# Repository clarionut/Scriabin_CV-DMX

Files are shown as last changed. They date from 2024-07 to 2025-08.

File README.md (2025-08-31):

# Scriabin_CV-DMX

A two channel CV-DMX converter based on an Arduino Pro Mini microcontroller.

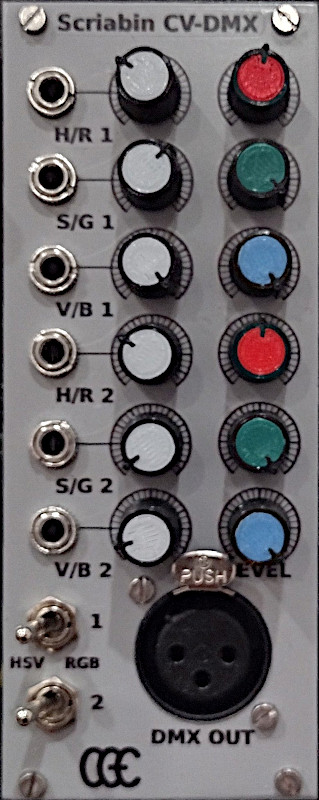
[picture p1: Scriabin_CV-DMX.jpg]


Named for the famously synaesthetic composer Scriabin, this module was designed to allow RGB LED PAR cans to be voltage controlled by an analogue modular synthesiser.
Each of the two channels can be controlled in the RGB (red, green, blue) or HSV (hue, saturation, value) colourspace, giving three control inputs per channel.
Each individual input has an attenuator for the CV input and an initial value potentiometer, so all colours are accessible without using the CV inputs.
In RGB mode the inputs control the red, green and blue channels individually, simple to understand but harder to use. Consequently HSV is probably the more useful colourspace, where setting the saturation and value initial values to maximum allows all hues to be accessed using just one CV input. This is also the reason for using HSV rather than the HSL (hue, saturation, lightness) colourspace, where the fully saturated colours are found at 100% saturation, 50% lightness.

There is also a 'hidden' mode on each channel (hidden mainly because of lack of space on the panel!). With the mode switch in the centre-off position the corresponding
channel will enter 'Scriabin mode' which converts the incoming Red/Hue CV into quantised light colours according to the scheme used by Scriabin in his ['Clavier à lumières'](https://en.wikipedia.org/wiki/Clavier_%C3%A0_lumi%C3%A8res).
The colours are: C - red; C# - purple; D - yellow; D# - flesh; E - sky blue; F - deep red; F# - bright blue; G - orange; G# - lilac; A - green; A# - rose; B - blue (this makes more sense if ordered by the circle of fifths - C - red; G - orange; D - yellow; A - green; E - sky blue; B - blue; F# - bright blue; C# - purple; G# - lilac; D# - flesh; A# - rose; F - deep red).
In this mode the input CV range should be adjusted so that successive octaves give the same colour. The tracking isn't perfect but should be good over about 2 1/2 octaves.
The Green/Saturation control has no effect in this mode but the Blue/Value control can be used to fade the light in and out, though the colours are increasingly inaccurate at low brightness.

The hardware is based on an Arduino Pro Mini driving a MAX485 RS-485 transceiver chip, as used in some of the commercial Arduino DMX shields.
The CV inputs have protection against out-of-range voltage inputs, but there is no isolation on the MAX485 (again like many of the commercial DMX shields).
Consequently the synthesiser and the light units must be powered from the same electrical circuit to avoid potentially dangerous voltages entering the synth.

The KiCad schematic and board layout use some custom symbols and footprints, so you will need to add my [kiCad_libraries](https://github.com/clarionut/kiCad_libraries)
before using these files.

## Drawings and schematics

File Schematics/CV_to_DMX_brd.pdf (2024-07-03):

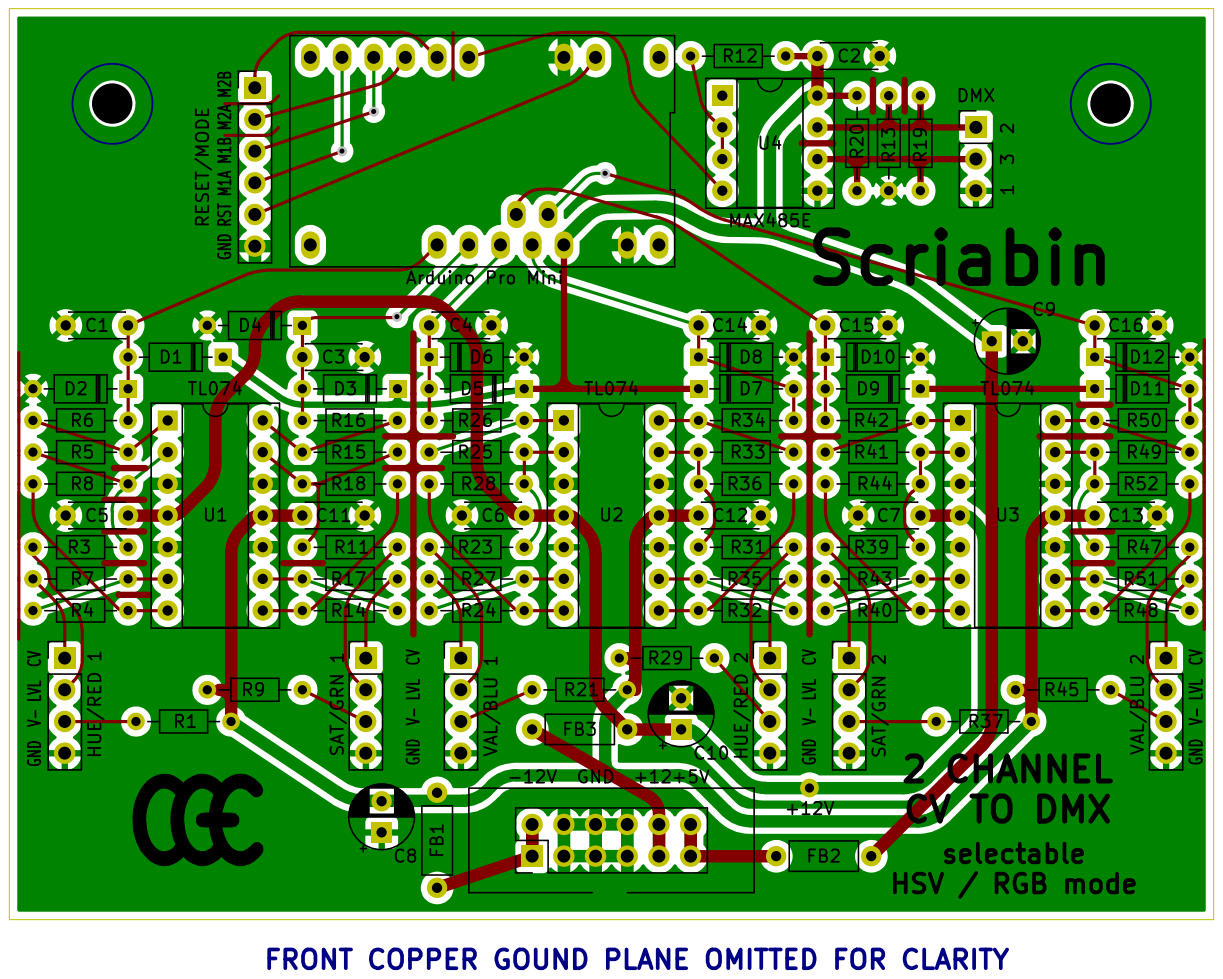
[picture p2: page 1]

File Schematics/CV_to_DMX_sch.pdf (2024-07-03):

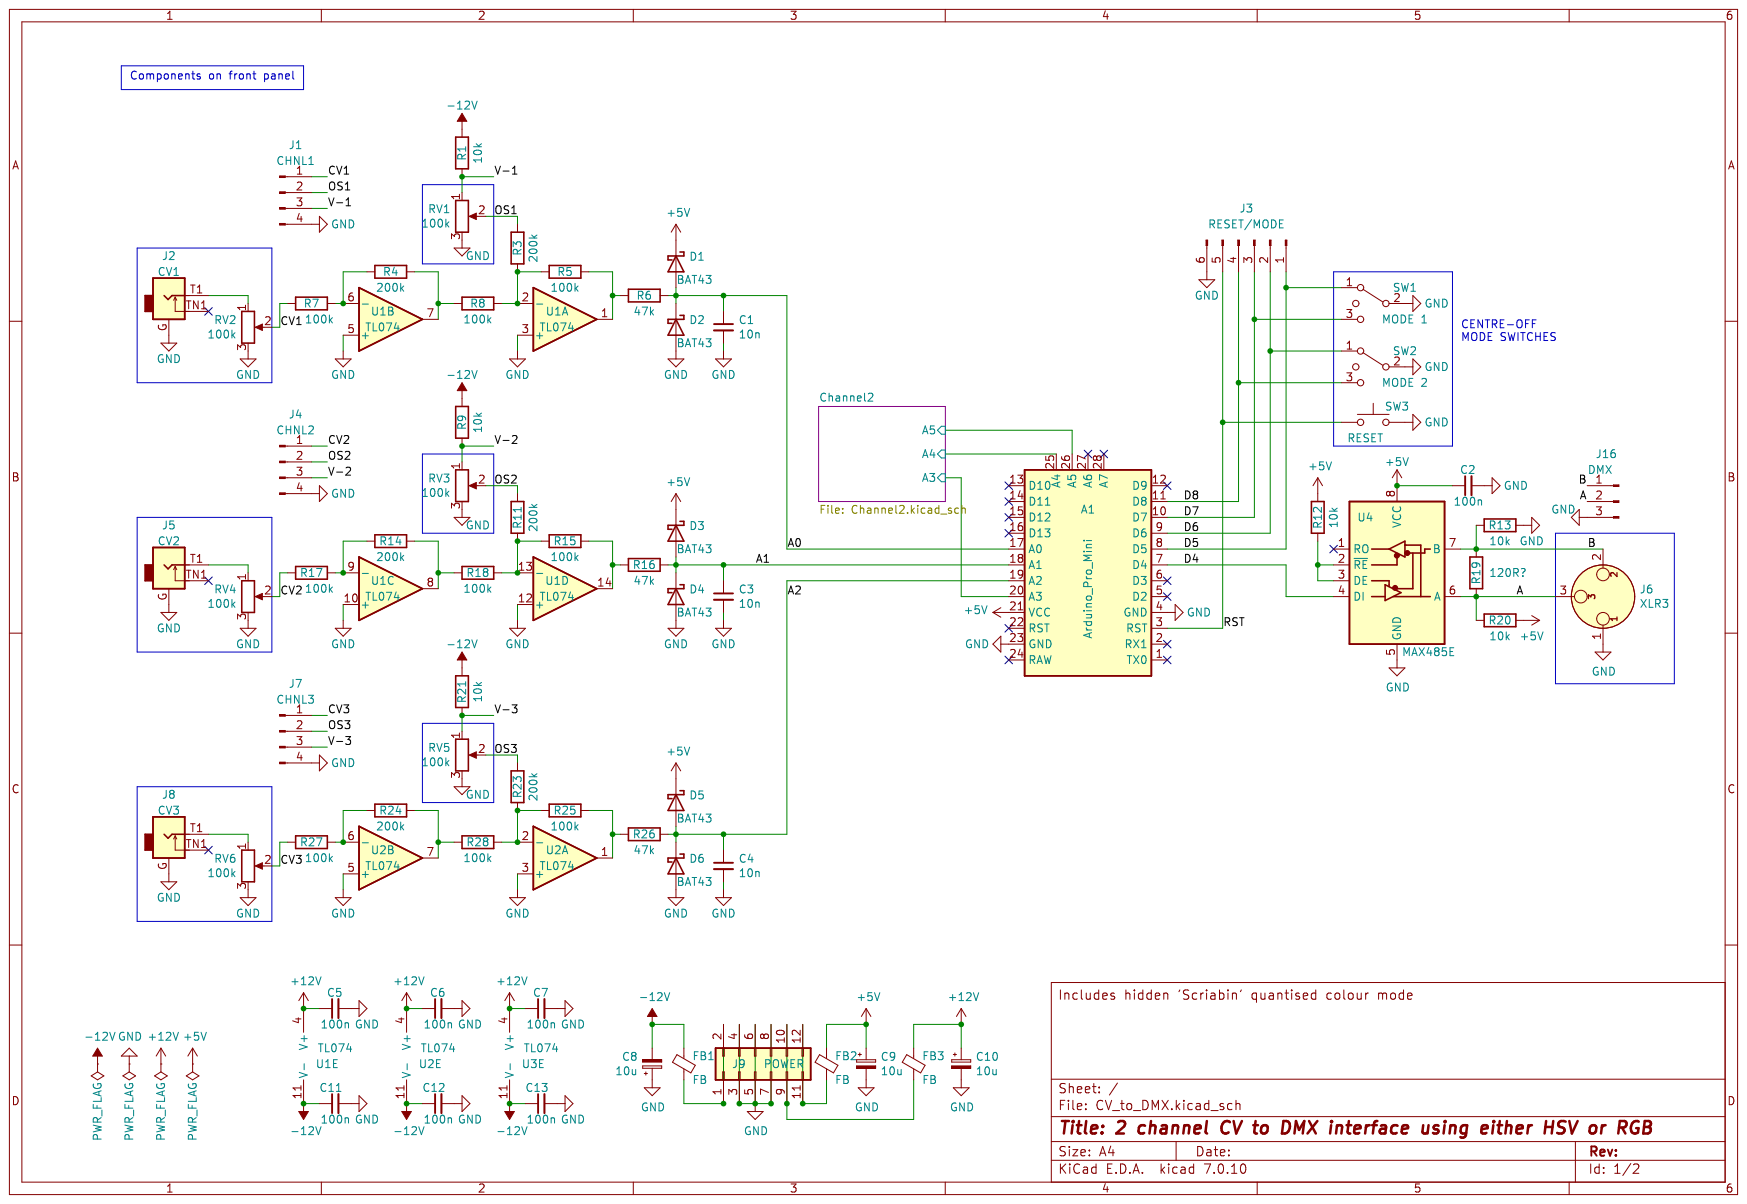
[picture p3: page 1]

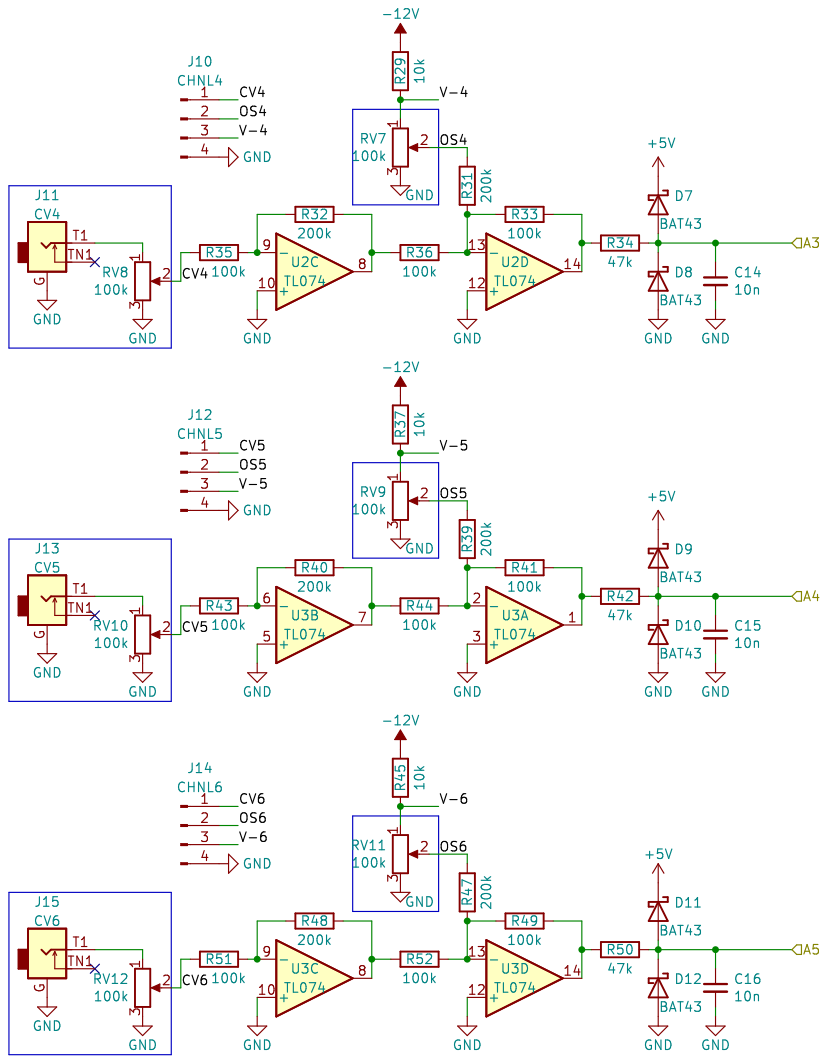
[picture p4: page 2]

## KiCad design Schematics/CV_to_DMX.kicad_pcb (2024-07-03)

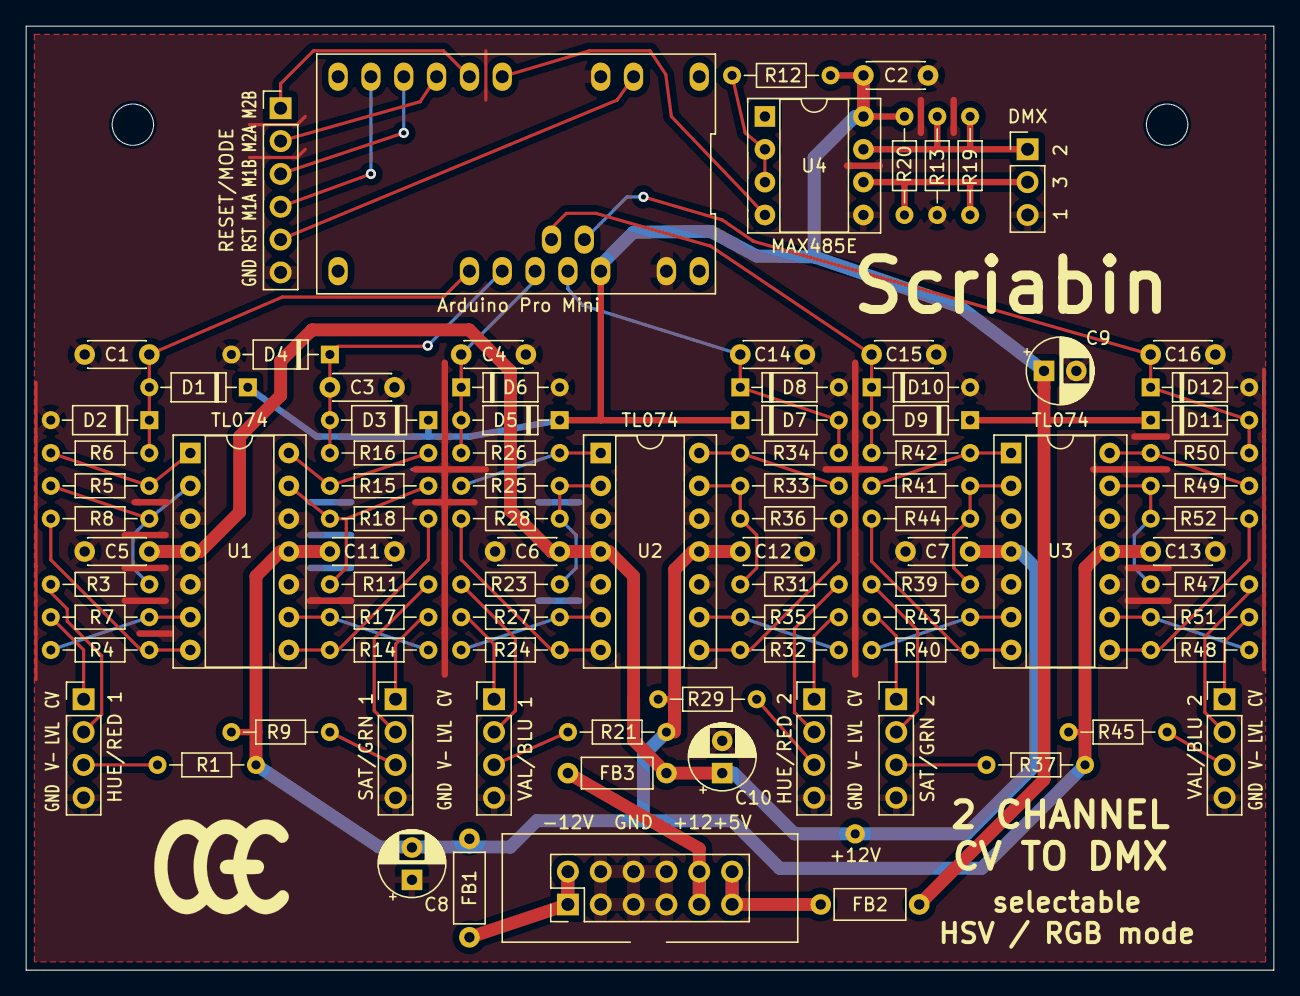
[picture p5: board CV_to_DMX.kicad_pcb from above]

Board: 2 copper layers, 96.5 x 73.0 mm, 92 parts (0 on the bottom side), 64 nets.

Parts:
+12V: +12V; TestPoint_THTPad_1.5x1.5mm_Drill0.7mm
A1: Arduino_Pro_Mini
C1, C3, C4, C14, C15, C16: 10n; C_Disc_D4.3mm_W1.9mm_P5.00mm
C2, C5, C6, C7, C11, C12, C13: 100n; C_Disc_D4.3mm_W1.9mm_P5.00mm
C8, C9, C10: 10u; CP_Radial_D5.0mm_P2.50mm
D1, D2, D3, D4, D5, D6, D7, D8, D9, D10, D11, D12: BAT43; D_DO-35_SOD27_P7.62mm_Horizontal
FB1, FB2, FB3: FB; L_Axial_L5.3mm_D2.2mm_P7.62mm_Horizontal_Vishay_IM-1
J1: CHNL1; PinHeader_1x04_P2.54mm_Vertical
J3: RESET/MODE; PinHeader_1x06_P2.54mm_Vertical
J4: CHNL2; PinHeader_1x04_P2.54mm_Vertical
J7: CHNL3; PinHeader_1x04_P2.54mm_Vertical
J9: POWER; Power_2x06
J10: CHNL4; PinHeader_1x04_P2.54mm_Vertical
J12: CHNL5; PinHeader_1x04_P2.54mm_Vertical
J14: CHNL6; PinHeader_1x04_P2.54mm_Vertical
J16: DMX; PinHeader_1x03_P2.54mm_Vertical
R1, R9, R12, R13, R20, R21, R29, R37, R45: 10k; R_Axial_DIN0204_L3.6mm_D1.6mm_P7.62mm_Horizontal
R3, R4, R11, R14, R23, R24, R31, R32, R39, R40, R47, R48: 200k; R_Axial_DIN0204_L3.6mm_D1.6mm_P7.62mm_Horizontal
R5, R7, R8, R15, R17, R18, R25, R27, R28, R33, R35, R36, R41, R43, R44, R49, R51, R52: 100k; R_Axial_DIN0204_L3.6mm_D1.6mm_P7.62mm_Horizontal
R6, R16, R26, R34, R42, R50: 47k; R_Axial_DIN0204_L3.6mm_D1.6mm_P7.62mm_Horizontal
R19: 120R?; R_Axial_DIN0204_L3.6mm_D1.6mm_P7.62mm_Horizontal
U1, U2, U3: TL074; DIP-14_W7.62mm_Socket
U4: MAX485E; DIP-8_W7.62mm_Socket

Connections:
+5V: A1.21 (VCC), C2.1, C9.1, D1.1 (K), D3.1 (K), D5.1 (K), D7.1 (K), D9.1 (K), D11.1 (K), FB2.1, R12.1, R20.1, U4.8 (VCC)
+12V: +12V.1, C5.1, C6.1, C7.1, C10.1, FB3.1, U1.4 (V+), U2.4 (V+), U3.4 (V+)
-12V: C8.2, C11.1, C12.1, C13.1, FB1.1, R1.1, R9.1, R21.1, R29.1, R37.1, R45.1, U1.11 (V-), U2.11 (V-), U3.11 (V-)
/A: J16.2, R19.1, R20.2, U4.6 (A)
/A0: A1.17 (A0), C1.1, D1.2 (A), D2.1 (K), R6.1
/A1: A1.18 (A1), C3.1, D3.2 (A), D4.1 (K), R16.1
/A2: A1.19 (A2), C4.1, D5.2 (A), D6.1 (K), R26.1
/B: J16.1, R13.2, R19.2, U4.7 (B)
/CV1: J1.1, R7.2
/CV2: J4.1, R17.2
/CV3: J7.1, R27.2
/Channel2/A3: A1.20 (A3), C14.1, D7.2 (A), D8.1 (K), R34.1
/Channel2/A4: A1.25 (A4), C15.1, D9.2 (A), D10.1 (K), R42.1
/Channel2/A5: A1.26 (A5), C16.1, D11.2 (A), D12.1 (K), R50.1
/Channel2/CV4: J10.1, R35.2
/Channel2/CV5: J12.1, R43.2
/Channel2/CV6: J14.1, R51.2
/Channel2/OS4: J10.2, R31.1
/Channel2/OS5: J12.2, R39.1
/Channel2/OS6: J14.2, R47.1
/Channel2/V-4: J10.3, R29.2
/Channel2/V-5: J12.3, R37.2
/Channel2/V-6: J14.3, R45.2
/D4: A1.7 (D4), U4.4 (DI)
/D5: A1.8 (D5), J3.1
/D6: A1.9 (D6), J3.2
/D7: A1.10 (D7), J3.3
/D8: A1.11 (D8), J3.4
/OS1: J1.2, R3.1
/OS2: J4.2, R11.1
/OS3: J7.2, R23.1
/RST: A1.3 (RST), J3.5
/V-1: J1.3, R1.2
/V-2: J4.3, R9.2
/V-3: J7.3, R21.2
GND: A1.4 (GND), A1.23 (GND), C1.2, C2.2, C3.2, C4.2, C5.2, C6.2, C7.2, C8.1, C9.2, C10.2, C11.2, C12.2, C13.2, C14.2, C15.2, C16.2, D2.2 (A), D4.2 (A), D6.2 (A), D8.2 (A), D10.2 (A), D12.2 (A), J1.4, J3.6, J4.4, J7.4, J9.3, J9.4, J9.5, J9.6, J9.7, J9.8, J10.4, J12.4, J14.4, J16.3, R13.1, U1.3 (+), U1.5 (+), U1.10 (+), U1.12 (+), U2.3 (+), U2.5 (+), U2.10 (+), U2.12 (+), U3.3 (+), U3.5 (+), U3.10 (+), U3.12 (+), U4.5 (GND)
unnamed: FB1.2, J9.1, J9.2
unnamed: FB3.2, J9.9, J9.10
unnamed: FB2.2, J9.11, J9.12
unnamed: R4.1, R8.2, U1.7
unnamed: R5.1, R6.2, U1.1
unnamed: R14.1, R18.2, U1.8
unnamed: R15.1, R16.2, U1.14
unnamed: R24.1, R28.2, U2.7
unnamed: R25.1, R26.2, U2.1
unnamed: R32.1, R36.2, U2.8
unnamed: R33.1, R34.2, U2.14
unnamed: R40.1, R44.2, U3.7
unnamed: R41.1, R42.2, U3.1
unnamed: R48.1, R52.2, U3.8
unnamed: R49.1, R50.2, U3.14
unnamed: R3.2, R5.2, R8.1, U1.2 (-)
unnamed: R4.2, R7.1, U1.6 (-)
unnamed: R14.2, R17.1, U1.9 (-)
unnamed: R11.2, R15.2, R18.1, U1.13 (-)
unnamed: R23.2, R25.2, R28.1, U2.2 (-)
unnamed: R24.2, R27.1, U2.6 (-)
unnamed: R32.2, R35.1, U2.9 (-)
unnamed: R31.2, R33.2, R36.1, U2.13 (-)
unnamed: R39.2, R41.2, R44.1, U3.2 (-)
unnamed: R40.2, R43.1, U3.6 (-)
unnamed: R48.2, R51.1, U3.9 (-)
unnamed: R47.2, R49.2, R52.1, U3.13 (-)
unnamed: R12.2, U4.2 (~RE), U4.3 (DE)

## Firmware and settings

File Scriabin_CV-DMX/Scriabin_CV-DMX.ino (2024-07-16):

/*
    Script to drive the Scriabin CV-DMX module

    The DMX_BASE and DMX_GAP defines below assume that the lamp(s) on the first channel
    start at DMX address 1 and those on the second channel start at address 9.
    BR_OFF is the offset of the overall brightness control from DMX_BASE, and
    R_OFF, G_OFF & B_OFF are the offsets from the base address of the individual
    red, green and blue controls in your lamps

    Please change these values if your DMX setup starts at a different address, and/or your
    lamps each require a larger range of, or different, addresses compared with mine.

    Analogue reads are performed twice to allow settling time in the Arduino's analogue
    multiplexer in order to reduce bleedthrough from one analogue input to the next.

    C G Earnshaw 16-11-23
*/

#include <DmxSimple.h>

#define DMX_BASE 1
#define DMX_GAP 8
#define BR_OFF 0
#define R_OFF 1
#define G_OFF 2
#define B_OFF 3

uint8_t chnl, anlg, addr;
long Red[2], Grn[2], Blu[2], H, S, V;
uint16_t oldRed[2] = {9999, 9999};
uint16_t oldGrn[2] = {9999, 9999};
uint16_t oldBlu[2] = {9999, 9999};
uint8_t scriabinClr[][3] = {
  { 0xFF, 0x00, 0x00 }, // C
  { 0xA0, 0x00, 0xFF }, // C#/Db
  { 0xFF, 0x72, 0x00 }, // D
  { 0xFF, 0x75, 0x6C }, // D#/Eb
  { 0x00, 0xFF, 0xF6 }, // E
  { 0x70, 0x00, 0x00 }, // F
  { 0x46, 0x00, 0xFF }, // F#/Gb
  { 0xFF, 0x56, 0x00 }, // G
  { 0xD7, 0x4B, 0xD8 }, // G#/Ab
  { 0x00, 0xFF, 0x00 }, // A
  { 0xFF, 0x57, 0x54 }, // A#/Bb
  { 0x00, 0x56, 0xFF }  // B/Cb
};


void setup () {
  DmxSimple.usePin(4);
  DmxSimple.maxChannel(DMX_GAP * 2 + DMX_BASE);

  // Pins for HSV/RGB switches
  pinMode(5, INPUT_PULLUP);
  pinMode(6, INPUT_PULLUP);
  pinMode(7, INPUT_PULLUP);
  pinMode(8, INPUT_PULLUP);

  Serial.begin(115200);
}

void loop () {
  // Check Mode switch
  anlg = 0;
  for (uint8_t i = 0; i < 2; i++) {
    addr = DMX_BASE + i * DMX_GAP;
    if (0 == digitalRead(5 + i)) {
      // RGB mode - read RGB directly  DmxSimple.write(DMX_BASE + BR_OFF, 255);
      DmxSimple.write(addr + BR_OFF, 255);
      analogRead(anlg);
      Red[i] = analogRead(anlg) >> 2;
      analogRead(++anlg);
      Grn[i] = analogRead(anlg) >> 2;
      analogRead(++anlg);
      Blu[i] = analogRead(anlg) >> 2;

    } else if (0 == digitalRead(7 + i)) {
      // HSV mode - read H S & V & convert to RGB
      DmxSimple.write(addr + BR_OFF, 255);
      analogRead(anlg);
      H = analogRead(anlg);
      analogRead(++anlg);
      S = analogRead(anlg);
      analogRead(++anlg);
      V = analogRead(anlg);
      HSV_2_RGB(H, S, V, &Red[i], &Grn[i], &Blu[i]);

    } else {
      // 'hidden' Scriabin mode
      analogRead(anlg);
      int tmp = ((analogRead(anlg) % 205) / 17) % 12;
      anlg += 2;
      analogRead(anlg);
      Red[i] = scriabinClr[tmp][0];
      Grn[i] = scriabinClr[tmp][1];
      Blu[i] = scriabinClr[tmp][2];
      DmxSimple.write(addr + BR_OFF, analogRead(anlg) / 4);
    }

    if (Red[i] != oldRed[i]) {
      DmxSimple.write(addr + R_OFF, Red[i]);
      oldRed[i] = Red[i];
    }
    if (Grn[i] != oldGrn[i]) {
      DmxSimple.write(addr + G_OFF, Grn[i]);
      oldGrn[i] = Grn[i];
    } 
    if (Blu[i] != oldBlu[i]) {
      DmxSimple.write(addr + B_OFF, Blu[i]);
      oldBlu[i] = Blu[i];
    }
    anlg = 3;
  }
}

void HSV_2_RGB(long hue, long sat, long val, long *RP, long *GP, long *BP) {
  // Calculate RGB values
  long R, G, B;
  if (0 == val) {
    // All channels are 0
    R = G = B = 0;

  } else if (0 == sat) {
    // 0 saturation => all channels are equal to V
    R = G = B = val;

  } else {
  // 1 - convert Hue into fully saturated RGB values
  // 2 - apply conversion for Saturation
  // 3 - reduce values according to Value
    uint16_t Satn = (1023 - sat);
    if (hue < 170) {  // 0 -> 169
      // Pure Red -> Yellow
      R = 1023;
      G = 1023 * hue / 170;
      B = Satn;

      G += (1023 - G) * Satn / 1023;

    } else if (hue < 341) {  // 170 - 340
      // Pure Yellow -> Green
      R = 1023 - 1023 * (hue - 170) / 171;
      G = 1023;
      B = Satn;

      R += (1023 - R) * Satn / 1023;

    } else if (hue < 512) {  // 341 -> 511
      // Pure Green -> Cyan
      R = Satn;
      G = 1023;
      B = 1023 * (hue - 341) / 171;

      B += (1023 - B) * Satn / 1023;

    } else if (hue < 682) {  // 512 -> 681
      // Pure Cyan -> Blue
      R = Satn;
      G = 1023 - 1023 * (hue - 512) / 170;
      B = 1023;

      G += (1023 - G) * Satn / 1023;

    } else if (hue < 853) {  // 682 -> 852
      // Pure Blue -> Magenta
      R = 1023 * (hue - 682) / 171;
      G = Satn;
      B = 1023;

      R += (1023 - R) * Satn / 1023;

    } else {  // (hue < 1024): 853 -> 1023
      // Pure Magenta -> Red
      R = 1023;
      G = Satn;
      B = 1023 - 1023 * (hue - 853) / 171;

      B += (1023 - B) * Satn / 1023;
    }
  }
  *RP = R * val / 1023 / 4;
  *GP = G * val / 1023 / 4;
  *BP = B * val / 1023 / 4;
}
